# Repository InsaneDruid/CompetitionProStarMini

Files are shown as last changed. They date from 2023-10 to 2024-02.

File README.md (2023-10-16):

# CompetitionProStarMini
A replacement PCB for the Competition Pro Mini and Pro Star Mini (with autofire) Joysticks to easily replace failing microswitches with modern parts. 

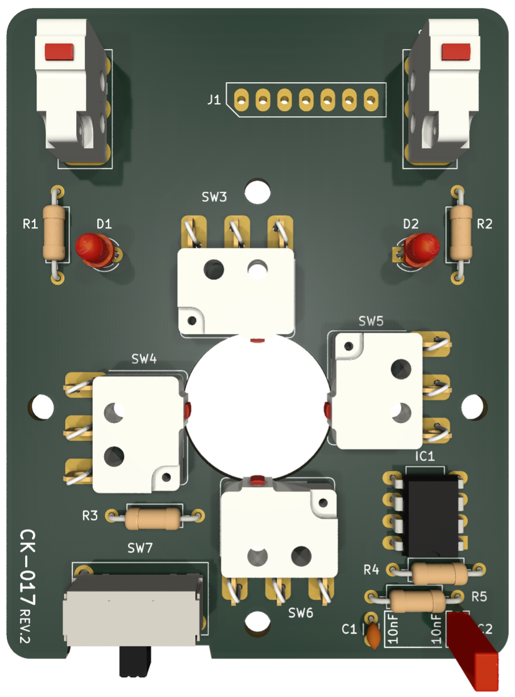
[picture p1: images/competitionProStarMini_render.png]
CompetitionProStarMini render


The Saia-Burgess F4T7-UL Microswitches used in this design provide up to 10 000 000 cycles of operation and allow the original stick gate to remain in place, giving the best overall experience.

A bent piece of copper wire can be used to further secure the directional switches to the pcb, using the provided mounting holes.

[Schematic](https://github.com/InsaneDruid/CompetitionProStarMini/blob/main/competitionProStarMini.pdf "Schematic")  

[Bill of Materials](https://htmlpreview.github.io/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 "Bill of Materials")

## The License
This work is licensed under a Creative Commons Attribution-ShareAlike 4.0 International License.  
See https://creativecommons.org/licenses/by-sa/4.0/.

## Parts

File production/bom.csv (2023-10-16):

Designator | Footprint | Quantity | Value | LCSC Part #
C1 | C_Disc_D3.0mm_W1.6mm_P2.50mm | 1 | 10nF
C2 | C_Rect_L4.0mm_W2.5mm_P2.50mm | 1 | 10nF
D1, D2 | LED_D3.0mm | 2 | LED
IC1 | DIP-8_W7.62mm_LongPads | 1 | LM555xN
R1, R2 | R_Axial_DIN0207_L6.3mm_D2.5mm_P10.16mm_Horizontal | 2 | 1K8
R3 | R_Axial_DIN0207_L6.3mm_D2.5mm_P10.16mm_Horizontal | 1 | 120
R4 | R_Axial_DIN0207_L6.3mm_D2.5mm_P10.16mm_Horizontal | 1 | 1M
R5 | R_Axial_DIN0207_L6.3mm_D2.5mm_P10.16mm_Horizontal | 1 | 100K
SW1, SW2 | Saia-Burgess_F4T7-UL | 2 | Saia-Burgess_F4T7-UL
SW3, SW4, SW5, SW6 | Saia-Burgess_F4T7-UL_lying | 4 | Saia-Burgess_F4T7-UL
SW7 | EG2308 | 1 | E-Switch EG 2308A

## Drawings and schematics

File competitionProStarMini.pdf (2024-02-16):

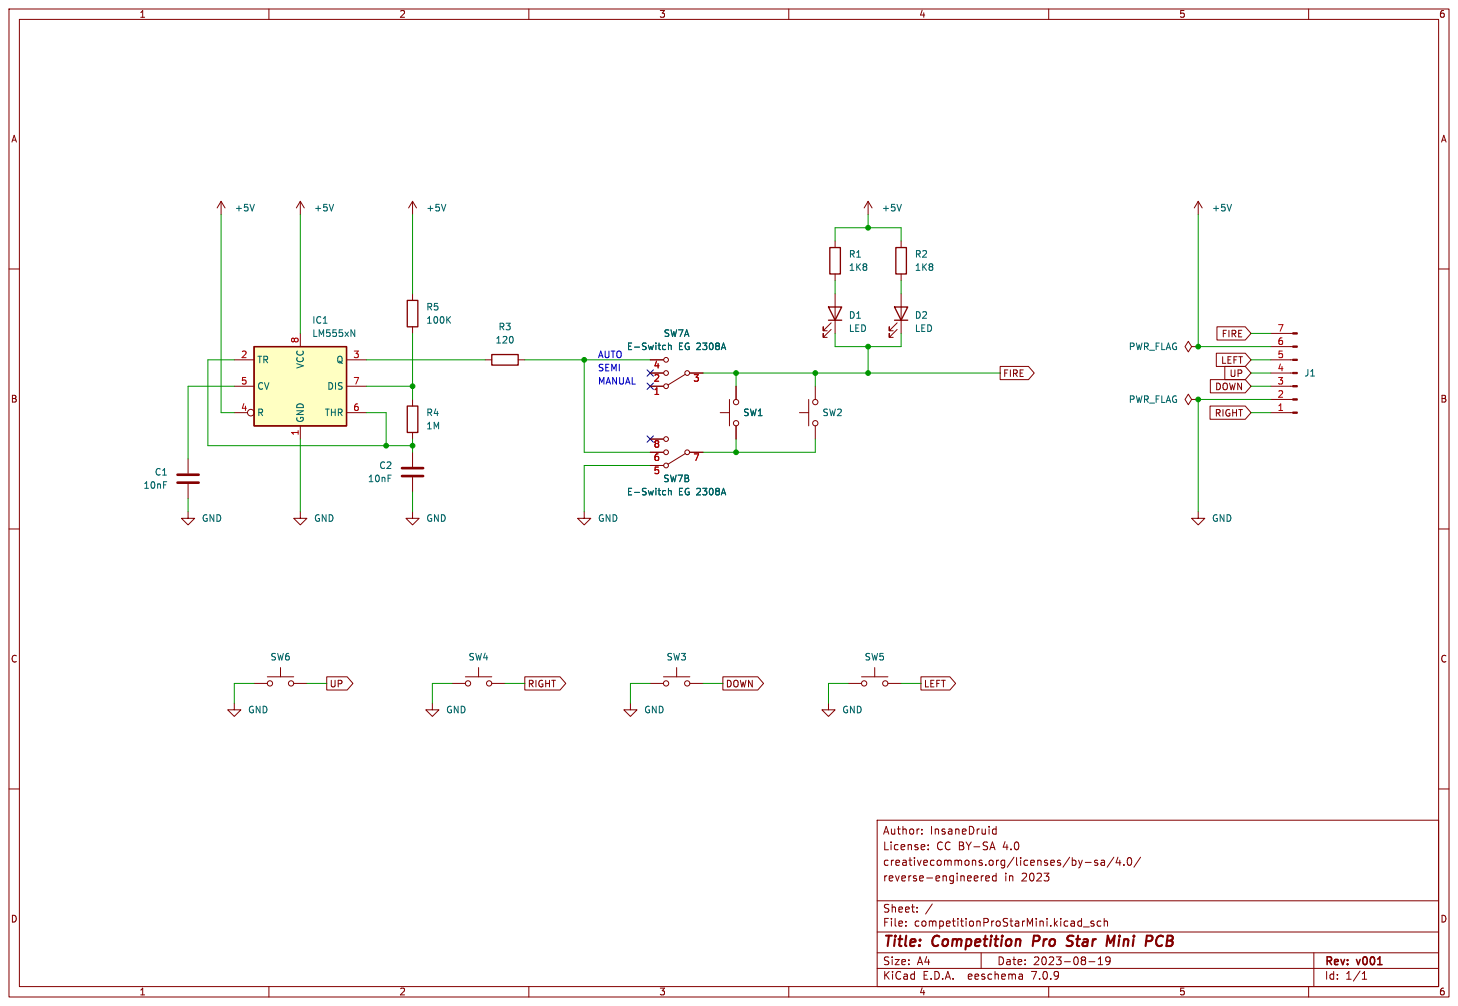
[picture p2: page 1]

Id: 1/1 Title: Competition Pro Star Mini PCB

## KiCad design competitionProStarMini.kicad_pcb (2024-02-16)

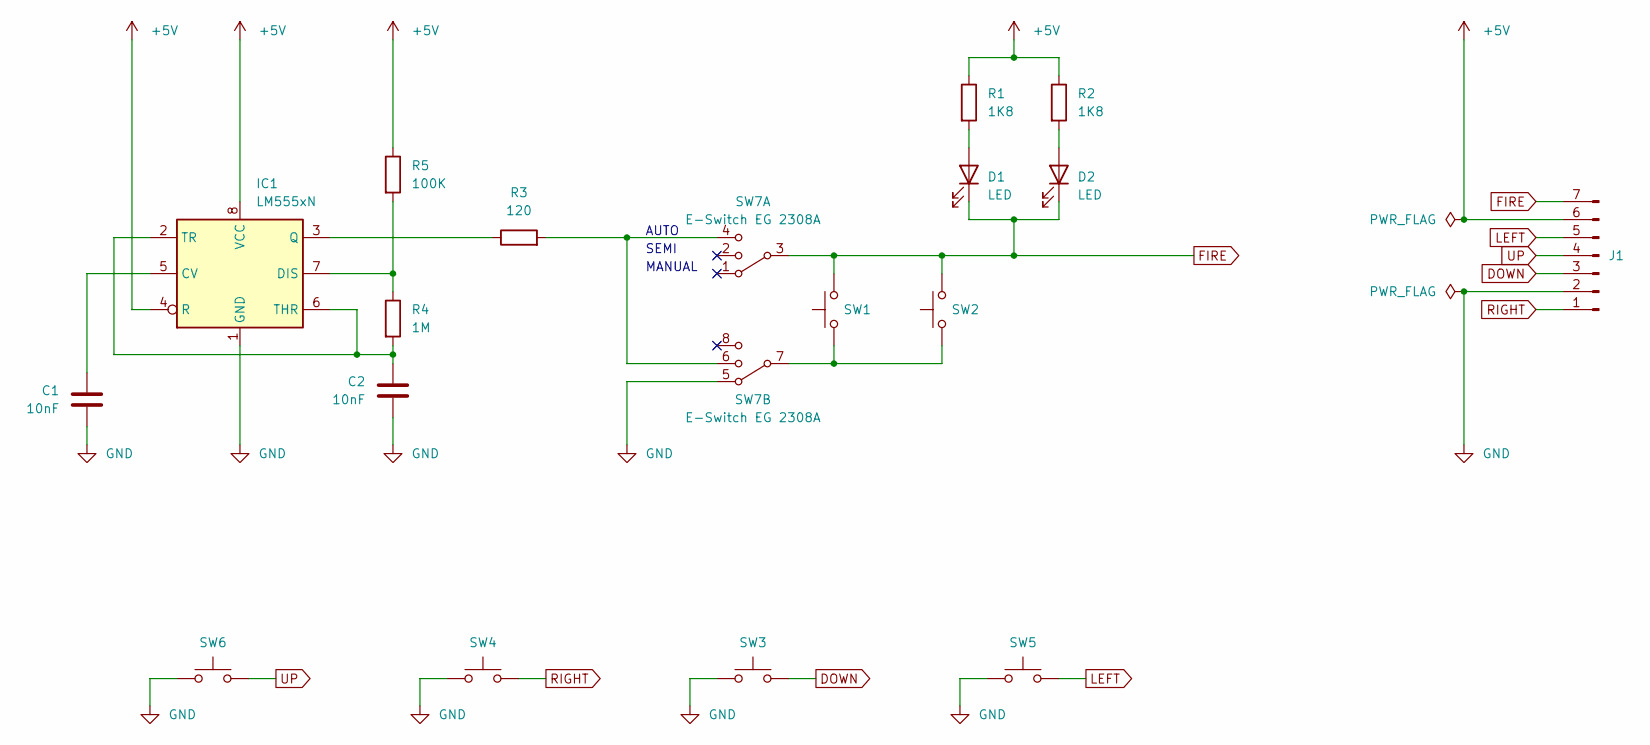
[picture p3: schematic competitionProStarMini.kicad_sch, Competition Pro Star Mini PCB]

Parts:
C1: 10nF; C_Disc_D3.0mm_W1.6mm_P2.50mm
C2: 10nF; C_Rect_L4.0mm_W2.5mm_P2.50mm
D1, D2: LED; LED_D3.0mm
IC1: LM555xN; DIP-8_W7.62mm_LongPads
J1: Conn_01x06_Pin; PinHeader_1x07_P2.54mm_Vertical
R1, R2: 1K8; R_Axial_DIN0207_L6.3mm_D2.5mm_P10.16mm_Horizontal
R3: 120; R_Axial_DIN0207_L6.3mm_D2.5mm_P10.16mm_Horizontal
R4: 1M; R_Axial_DIN0207_L6.3mm_D2.5mm_P10.16mm_Horizontal
R5: 100K; R_Axial_DIN0207_L6.3mm_D2.5mm_P10.16mm_Horizontal
SW1, SW2: Saia-Burgess_F4T7-UL
SW3, SW4, SW5, SW6: Saia-Burgess_F4T7-UL; Saia-Burgess_F4T7-UL_lying
SW7: E-Switch EG 2308A; EG2308

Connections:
+5V: IC1.4 (R), IC1.8 (VCC), J1.6, R1.1, R2.1, R5.1
DOWN: J1.3, SW3.2
FIRE: D1.1 (K), D2.1 (K), J1.7, SW1.2, SW2.2, SW7.3
GND: C1.1, C2.1, IC1.1 (GND), J1.2, SW3.1, SW4.1, SW5.1, SW6.2, SW7.5
LEFT: J1.5, SW5.2
unnamed: D1.2 (A), R1.2
unnamed: D2.2 (A), R2.2
unnamed: C1.2, IC1.5 (CV)
unnamed: IC1.7 (DIS), R4.1, R5.2
unnamed: IC1.3 (Q), R3.1
unnamed: C2.2, IC1.2 (TR), IC1.6 (THR), R4.2
unnamed: R3.2, SW7.4, SW7.6
unnamed: SW1.1, SW2.1, SW7.7
RIGHT: J1.1, SW4.2
UP: J1.4, SW6.1

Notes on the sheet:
AUTO
SEMI
MANUAL

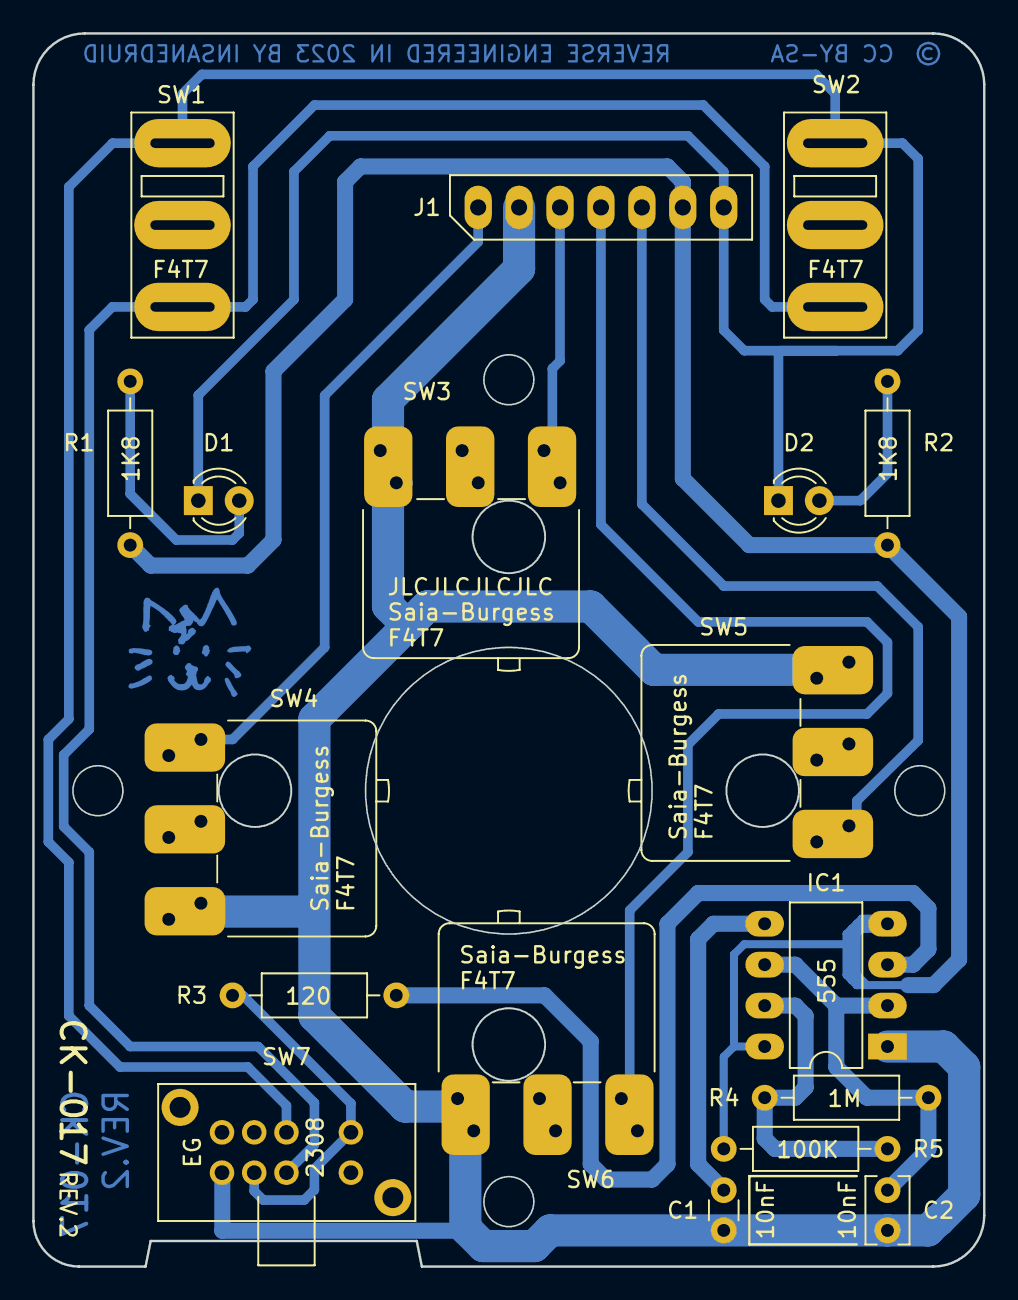
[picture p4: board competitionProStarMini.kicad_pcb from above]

Board: 2 copper layers, 59.0 x 76.5 mm, 18 parts (0 on the bottom side), 15 nets.

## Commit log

2023-10-30 render image & fablayer cleanup
    cleaned up and overhauled the fab layer of the pcb
    added a slightly cleaner and bigger render image
    [competitionProStarMini.kicad_pcb]
2024-02-16 kicad drawing sheet fixes
    fixed license links in drawing sheets to match board prints, readme and project
    [competitionProStarMini.kicad_pcb, competitionProStarMini.kicad_sch]

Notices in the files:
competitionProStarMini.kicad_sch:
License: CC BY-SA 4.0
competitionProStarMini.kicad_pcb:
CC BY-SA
